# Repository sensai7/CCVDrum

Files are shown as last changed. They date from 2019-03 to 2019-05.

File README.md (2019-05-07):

# CCVDrum
Energia code and Kicad files for a Korg Volca Drum MIDI CC board

Board

In the Korg Volca Drum there's a hidden menu when you press the edit/step to 
change five adittional settings for each part and layer: bit resolution, 
overdrive, wave folding, pan, and pre-amp gain.

This repository contains the code, schematic, and PCB files to build and 
program a circuit board to control the 'hidden' paramenters from a Korg Volca 
Drum, having one dedicated knob control for each one and being able to select 
the first, second, or both layers with the provided push buttons. 
The circuit is based on a MSP430G2553, a common and cheap microprocessor from 
Texas Instruments, and it's coded in Energia, an Arduino port for TI 
processors, bringing the simplicity of the Wiring language and the huge 
Arduino community projects available to the Texas Instruments MCU ecosystem.

Some features:

* The board is designed to fit inside a 1590B enclosure, a really common 
and cheap enclosure model for guitar pedals.
* The power plug is a 2.1mm barrel jack and with the current Voltage Regulator 
model, Voltages from 5V to 20V are fine.
* There's a optional MIDI input to use as MIDI thru if you need to chain your 
devices.

The Volca must be [up to date](https://www.korg.com/us/support/download/product/0/809/#software), or at least in version 1.11 which changed a critical bug on the MIDI implementation (BIT knob won't work and the others would be changed). It must also be set in Split Channel Mode, the CC messages needed (BIT, DRV,... etc) are not available in the Single Channel Mode. My unit came with Split mode by default, but to check and change it, turn it on while holding ●RECORD, then press one of the channels to select it, then press it again to change it to channels 1-6. Press the ●RECORD button again when your unit's screen shows [MID 1--6](https://i.imgur.com/e5hpA2r.jpg).

The easiest way to flash a different firmware would be owning a MSP430G2 
(MSP-EXP430G2) launchpad, or the newer MSP430G2ET (MSP-EXP430G2ET) LaunchPad, 
place your MCU in the LaunchPad socket and flash the new code using Energia. 

Useful links

 * Korg Volca Drum official site: https://www.korg.com/us/products/dj/volca_drum/
 * Energia Project site: http://energia.nu
 * KiCad footprints and 3D models http://smisioto.no-ip.org/elettronica/kicad/kicad-en.htm

Datasheets

 * MSP430G2553 Mixed Signal Microcontroller http://www.ti.com/lit/ds/symlink/msp430g2553.pdf
 * 6N139 High Speed Optocoupler https://www.vishay.com/docs/83605/6n139.pdf
 * 74HC14 Hex inverting Schmitt trigger https://assets.nexperia.com/documents/data-sheet/74HC_HCT14.pdf
 * LM1117IMP-3.3 LDO Voltage Regulator http://www.ti.com/lit/ds/symlink/lm1117.pdf
 
 (Only in older versions):
 * AMS1117-3.3 1A LOW DROPOUT VOLTAGE REGULATOR http://www.advanced-monolithic.com/pdf/ds1117.pdf
 * 74AUP1G17 SINGLE SCHMITT-TRIGGER BUFFER https://www.diodes.com/assets/Datasheets/74AUP1G17.pdf

TODO

 * Fix minor bugs

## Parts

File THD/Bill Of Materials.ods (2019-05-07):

Disclaimer: The purchase links are not really curated, you can most probably find the same items for cheaper if you browse more alternatives, you usually have everything you need in Tayda/ Ebay / Aliexpress and most importantly, your local electronic supplies store.
 | I’m not associated in any way with any of the vendors of any of these components.
Designator | Package or sizes | Component | Value or model | purchase link | alt link | Comments
C1 | THT 5.00mm | Capacitor | 10n |  |  | I suggest getting the capacitors at your local electronic supply store so you avoid buying 100+ pieces of the same value. Alternatively the “assorted capacitor” packs online are handy.
C2 | THT 5.00mm | Capacitor | 330n
C3 | THT 5.00mm | Capacitor | 100n
C4 | THT 5.00mm | Capacitor | 10n
C5 | THT 5.00mm | Capacitor | 100n
D1 | LED 3mm | LED | LED
D2 | LED 3mm | LED | LED
D3 | LED 3mm | LED | LED
D4 | LED 3mm | LED | LED
D5 | LED 3mm | LED | LED
D6 | LED 3mm | LED | LED
J1 | Barrel jack | Barrel jack | Barrel jack
J4 | DIN-5 | Female MIDI | MIDI_in | https://www.ebay.com/itm/2pcs-PCB-Panel-PC-Mount-Right-Angle-MIDI-Female-DIN5-DIN-5-Pin-Connector-Socket/300632125472
J5 | DIN-5 | Female MIDI | MIDI_out
R1 | R_Axial | Resistor | 47k
R2 | R_Axial | Resistor | 68 |  |  | The value RLED depends on the LED model, the color of the LED and the luminosity you want. Take in consideration the MSP430 can only output up to 6mA per pin
R3 | R_Axial | Resistor | 220 |  |  | RLED = (3.3 – Vdrop) / I
R4 | R_Axial | Resistor | RLED |  |  | Assuming 2V drop from a red led @ I = 5mA
R5 | R_Axial | Resistor | RLED |  |  | RLED = (3.3 – 2) / 5mA = 260
 |  |  |  |  |  | To choose an standard value from E24 resistors RLED =270 ohm (or 300/330ohm) to ensure ILED is between 4ma and 5ma
R7 | R_Axial | Resistor | RLED
R8 | R_Axial | Resistor | 68
R9 | R_Axial | Resistor | 270
R10 | R_Axial | Resistor | RLED
R11 | R_Axial | Resistor | RLED
R12 | R_Axial | Resistor | RLED
RV1 | alps-rk09k1130ah1 | Potentiometer | 10k | https://www.taydaelectronics.com/potentiometer-variable-resistors/rotary-potentiometer/linear/10k-ohm-linear-taper-potentiometer-round-knurled-plastic-shaft-p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 | https://www.ebay.com/itm/20PCS-RV09-Type-Vertical-Adjustable-Potentiometer-Variable-Resistor-10K/183206858753 | Tayda has also some nice metal-knob models. The value is not really relevant, as long as you keep it from 1k to 100k to avoid weird behaviors
RV2 | alps-rk09k1130ah1 | Potentiometer | 10k
RV3 | alps-rk09k1130ah1 | Potentiometer | 10k
RV4 | alps-rk09k1130ah1 | Potentiometer | 10k
RV5 | alps-rk09k1130ah1 | Potentiometer | 10k
RV6 | alps-rk09k1130ah1 | Potentiometer | 10k
SW1 | 6mm THT vertical | Push button | 6mm | https://www.aliexpress.com/item/20PCS-4Pin-6-6-Micro-Tact-Push-Button-Switches-DIP-6x6x4-3-5-6-8-10/32963297826.html | https://www.ebay.com/itm/20PCS-6-6-6mm-Tact-Tactile-Push-Button-Switch-DIP-4Pin-NEW/391462868531
SW2 | 6mm THT vertical | Push button | 6mm
U1 | DIP-20 | MCU | MSP430G2533 | https://www.ebay.com/itm/1pcs-M430G2553-ORIGINAL-MSP430G2553IN20-MSP430G2553-MCU-IC-TI-DIP-20-NEW/172847287897 |  | Any 20-pin MSP430G2 “should” work too
U2 | TO-220-3 | LDO Regulator | LM1117IMP-3.3
U3 | DIP-14 | Hex schmitt trigger | 74HC14

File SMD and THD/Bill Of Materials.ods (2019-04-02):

Disclaimer: The purchase links are not really curated, you can most probably find the same items for cheaper if you browse more alternatives, you usually have everything you need in Tayda/ Ebay / Aliexpress and most importantly, your local electronic supplies store.
 | I’m not associated in any way with any of the vendors of any of these components.
Designator | Package or sizes | Component | Value or model | purchase link | alt link | Comments
C1 | THT 5.00mm | Capacitor | 330n |  |  | I suggest getting the capacitors at your local electronic supply store so you avoid buying 100+ pieces of the same value. Alternatively the “assorted capacitor” packs online are handy.
C2 | THT 5.00mm | Capacitor | 100n
C3 | THT 5.00mm | Capacitor | 1n
C4 | THT 5.00mm | Capacitor | 10n
C5 | THT 5.00mm | Capacitor | 100n
D1 | 0805 | LED | LED | https://www.ebay.com/itm/100PCS-White-Red-Blue-Yellow-Orange-SMD-LED-0805-2mm-1-2mm-NEW/232397105931 |  | Since it’s a small component the pads have been made bigger. A slightly bigger LED would probably fit as well.
D2 | 0805 | LED | LED
D3 | 0805 | LED | LED
D4 | 0805 | LED | LED
D5 | 0805 | LED | LED
D6 | 0805 | LED | LED
J1 | USB_Micro-B | Female USB | USB_B_μ | https://www.ebay.com/itm/10Pcs-Micro-USB-Type-B-Female-5Pin-Horns-type-Socket-PCB-Solder-Connector/171349298330 |  | Take in consideration the current footprint as two long drill holes to fir those metal tips on the sides
J2 | 2.54mm pitch | Pin Header | 1x4 Vertical | www.ebay.com/itm/10PCS-40Pin-2-54mm-Single-Row-Straight-Male-Pin-Header-Strip-PBC-Ardunio-GM/262136738129 |  | Not necessary if you don’t plan to mod or re-program the MCU yourself
J3 | DIN-5 | Female MIDI | MIDI_out | https://www.ebay.com/itm/2pcs-PCB-Panel-PC-Mount-Right-Angle-MIDI-Female-DIN5-DIN-5-Pin-Connector-Socket/300632125472 |  | The footprint has enough clearance in case you purchase those slightly bigger versions
R1 | R_Axial | Resistor | 47k
R2 | R_Axial | Resistor | RLED |  |  | The value RLED depends on the LED model, the color of the LED and the luminosity you want. Take in consideration the MSP430 can only output up to 6mA per pin
R3 | R_Axial | Resistor | RLED |  |  | RLED = (3.3 – Vdrop) / I
R4 | R_Axial | Resistor | RLED |  |  | Assuming 2V drop from a red led @ I = 6mA
R5 | R_Axial | Resistor | RLED |  |  | RLED = (3.3 – 2) / 6mA = 133.3 ohm
R6 | R_Axial | Resistor | RLED |  |  | To choose an standard value RLED =150 ohm to ensure ILED is between 5ma and 6ma
R7 | R_Axial | Resistor | RLED
R8 | R_Axial | Resistor | 68ohm
R9 | R_Axial | Resistor | 68ohm
R10 | R_Axial | Resistor | 1k
RV1 | alps-rk09k1130ah1 | Potentiometer | 10k | https://www.taydaelectronics.com/potentiometer-variable-resistors/rotary-potentiometer/linear/10k-ohm-linear-taper-potentiometer-round-knurled-plastic-shaft-p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 | https://www.ebay.com/itm/20PCS-RV09-Type-Vertical-Adjustable-Potentiometer-Variable-Resistor-10K/183206858753 | Tayda has also some nice metal-knob models. The value is not really relevant, as long as you keep it from 1k to 100k to avoid weird behaviors
RV2 | alps-rk09k1130ah1 | Potentiometer | 10k
RV3 | alps-rk09k1130ah1 | Potentiometer | 10k
RV4 | alps-rk09k1130ah1 | Potentiometer | 10k
RV5 | alps-rk09k1130ah1 | Potentiometer | 10k
RV6 | alps-rk09k1130ah1 | Potentiometer | 10k
SW1 | 6mm THT vertical | Push button | 6mm | https://www.aliexpress.com/item/20PCS-4Pin-6-6-Micro-Tact-Push-Button-Switches-DIP-6x6x4-3-5-6-8-10/32963297826.html | https://www.ebay.com/itm/20PCS-6-6-6mm-Tact-Tactile-Push-Button-Switch-DIP-4Pin-NEW/391462868531
SW2 | 7mm THT vertical | Push button | 6mm
U1 | DIP-20 | MCU | MSP430G2533 | https://www.ebay.com/itm/1pcs-M430G2553-ORIGINAL-MSP430G2553IN20-MSP430G2553-MCU-IC-TI-DIP-20-NEW/172847287897 |  | Any 20-pin MSP430G2 “should” work too
U2 | SOT-223-3 | LDO Regulator | AMS1117-3.3 | https://www.ebay.com/itm/10Pcs-AMS1117-3-3-LM1117-3-3V-1A-SOT-223-Voltage-Regulator-Nice-WD/312443168863
U3 | SOT-23-5 | Triggered Buffer | 74AUP1G17 | https://www.ebay.com/itm/10pcs-PJ-74AUP1G17GW-125-SOT-23-5-Low-power-Schmitt-trigger-buffer/253831344705 |  | Any Buffer with the same package and pinout suited for 3.3V operation should work just as well

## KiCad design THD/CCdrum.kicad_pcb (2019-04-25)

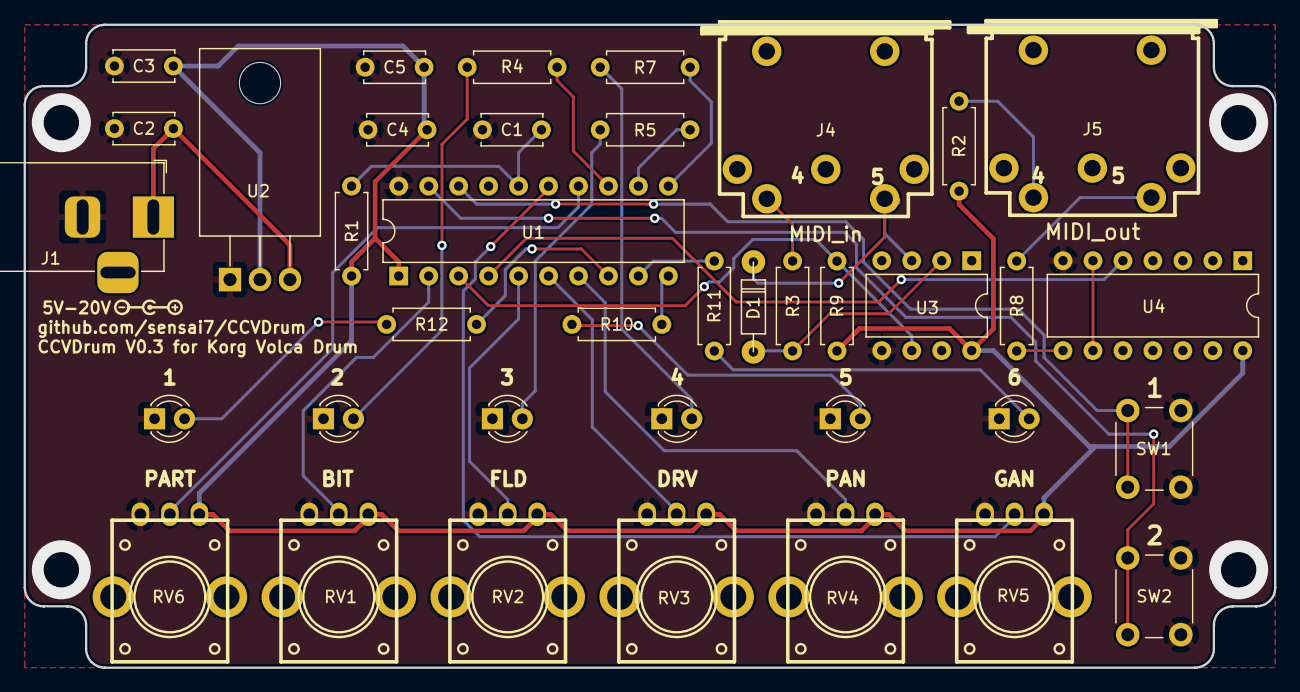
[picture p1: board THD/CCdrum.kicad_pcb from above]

Board: 2 copper layers, 106.0 x 54.5 mm, 38 parts (0 on the bottom side), 33 nets.

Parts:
C1, C4: 10; C_Disc_D5.0mm_W2.5mm_P5.00mm
C2: 330; C_Disc_D5.0mm_W2.5mm_P5.00mm
C3, C5: 100; C_Disc_D5.0mm_W2.5mm_P5.00mm
D1: 1N4148; diode_do35
D2: 1; LED_D3.0mm
D3: 2; LED_D3.0mm
D4: 3; LED_D3.0mm
D5: 4; LED_D3.0mm
D6: 5; LED_D3.0mm
D7: 6; LED_D3.0mm
J1: Barrel_Jack; BarrelJack_Horizontal
J4: MIDI_in; din-5
J5: MIDI_out; din-5
R1: 47k; R_Axial_DIN0207_L6.3mm_D2.5mm_P7.62mm_Horizontal
R2, R8: 68; R_Axial_DIN0207_L6.3mm_D2.5mm_P7.62mm_Horizontal
R3: 220; R_Axial_DIN0207_L6.3mm_D2.5mm_P7.62mm_Horizontal
R4, R5, R7, R10, R11, R12: RLED; R_Axial_DIN0207_L6.3mm_D2.5mm_P7.62mm_Horizontal
R9: 270; R_Axial_DIN0207_L6.3mm_D2.5mm_P7.62mm_Horizontal
RV1, RV2, RV3, RV4, RV5, RV6: 10k; trimmer_alps-rk09k1130ah1
SW1, SW2: SW_Push; SW_PUSH_6mm_H4.3mm
U1: MSP430G2533; DIP-20_W7.62mm
U2: LM1117IMP-3.3; TO-220-3_Horizontal_TabDown
U3: 6N139; DIP-8_W7.62mm
U4: 74HC14; DIP-14_W7.62mm

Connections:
+3V3: C3.1, C4.1, C5.1, R1.1, R2.1, R9.1, RV1.1, RV2.1, RV3.1, RV4.1, RV5.1, RV6.1, U1.1, U2.2, U3.8, U4.14
+5V: C2.1, J1.1, U2.3
BIT: RV1.2, U1.2
DRV: RV3.2, U1.6
FLD: RV2.2, U1.5
GAN: RV6.2, U1.14
GND: C1.2, C2.2, C3.2, C4.2, C5.2, D2.1, D3.1, D4.1, D5.1, D6.1, D7.1, J1.2, RV1.3, RV2.3, RV3.3, RV4.3, RV5.3, RV6.3, SW1.1, SW2.1, U1.20, U2.1, U3.5, U4.7
LED_P1: R4.1, U1.13
LED_P2: R5.1, U1.12
LED_P3: R7.1, U1.11
LED_P4: R10.1, U1.10
LED_P5: R11.1, U1.9
LED_P6: R12.1, U1.8
unnamed: C1.1, R1.2, U1.16
unnamed: D1.1, R3.1, U3.2
unnamed: D1.2, J4.5, U3.3
unnamed: D2.2, R4.2
unnamed: D3.2, R5.2
unnamed: D4.2, R7.2
unnamed: D5.2, R10.2
unnamed: D6.2, R11.2
unnamed: D7.2, R12.2
unnamed: J4.4, R3.2
unnamed: J5.4, R2.2
unnamed: J5.5, R8.1
unnamed: R8.2, U4.8
unnamed: U4.6, U4.9
PAN: RV4.2, U1.7
PART: RV5.2, U1.15
PUSH_L1: SW1.2, U1.18
PUSH_L2: SW2.2, U1.19
RXD: R9.2, U1.3, U3.6
TXD: U1.4, U4.5

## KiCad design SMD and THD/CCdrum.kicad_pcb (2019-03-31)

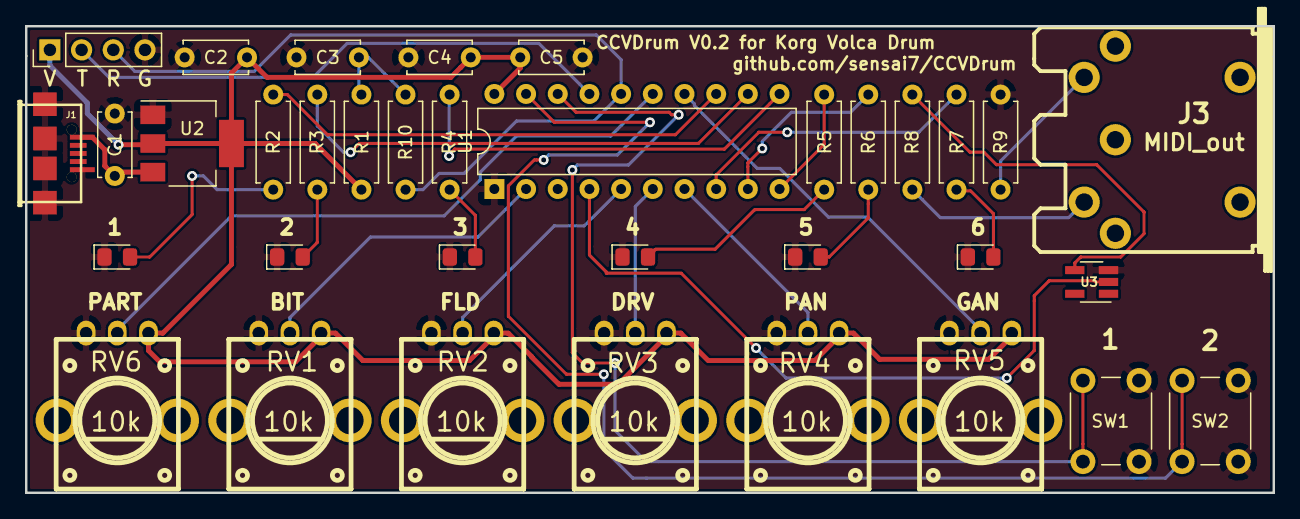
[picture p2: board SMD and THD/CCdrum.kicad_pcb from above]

Board: 2 copper layers, 100.0 x 37.4 mm, 35 parts (0 on the bottom side), 30 nets.

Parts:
C1: 330; C_Disc_D5.0mm_W2.5mm_P5.00mm
C2, C5: 100; C_Disc_D5.0mm_W2.5mm_P5.00mm
C3: 1n; C_Disc_D5.0mm_W2.5mm_P5.00mm
C4: 10; C_Disc_D5.0mm_W2.5mm_P5.00mm
D1: 1; LED_0805_2012Metric_Pad1.15x1.40mm_HandSolder
D2: 2; LED_0805_2012Metric_Pad1.15x1.40mm_HandSolder
D3: 3; LED_0805_2012Metric_Pad1.15x1.40mm_HandSolder
D4: 4; LED_0805_2012Metric_Pad1.15x1.40mm_HandSolder
D5: 5; LED_0805_2012Metric_Pad1.15x1.40mm_HandSolder
D6: 6; LED_0805_2012Metric_Pad1.15x1.40mm_HandSolder
J1: USB_B_μ; conn_usb_B_micro_smd-2
J2: Program; PinHeader_1x04_P2.54mm_Vertical
J3: MIDI_out; din-5
R1: 47k; R_Axial_DIN0207_L6.3mm_D2.5mm_P7.62mm_Horizontal
R2, R3, R4, R5, R6, R7: RLED; R_Axial_DIN0207_L6.3mm_D2.5mm_P7.62mm_Horizontal
R8, R9: 68; R_Axial_DIN0207_L6.3mm_D2.5mm_P7.62mm_Horizontal
R10: 1k; R_Axial_DIN0207_L6.3mm_D2.5mm_P7.62mm_Horizontal
RV1, RV2, RV3, RV4, RV5, RV6: 10k; trimmer_alps-rk09k1130ah1
SW1, SW2: SW_Push; SW_PUSH_6mm_H4.3mm
U1: MSP430G2533; DIP-20_W7.62mm
U2: AMS1117-3.3; SOT-223-3_TabPin2
U3: 74AUP1G17; SOT-23-5_HandSoldering

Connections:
+3V3: C2.1, C4.1, C5.1, J2.1, R1.1, RV1.1, RV2.1, RV3.1, RV4.1, RV5.1, RV6.1, U1.20, U2.2
+5V: C1.1, J1.1, U2.3
BIT: RV1.2, U1.2
DRV: RV3.2, U1.6
FLD: RV2.2, U1.5
GAN: RV5.2, U1.14
GND: C1.2, C2.2, C3.2, C4.2, C5.2, D1.1, D2.1, D3.1, D4.1, D5.1, D6.1, J1.5, J2.4, R9.2, RV1.3, RV2.3, RV3.3, RV4.3, RV5.3, RV6.3, SW1.1, SW2.1, U1.1, U2.1, U3.3
LED_P1: R2.1, U1.13
LED_P2: R3.1, U1.12
LED_P3: R4.1, U1.11
LED_P4: R5.1, U1.10
LED_P5: R6.1, U1.9
LED_P6: R7.1, U1.8
unnamed: C3.1, R1.2, R10.2
unnamed: D1.2, R2.2
unnamed: D2.2, R3.2
unnamed: D3.2, R4.2
unnamed: D4.2, R5.2
unnamed: D5.2, R6.2
unnamed: D6.2, R7.2
unnamed: J3.4, R9.1
unnamed: J3.5, R8.1
unnamed: R8.2, U3.4
PAN: RV4.2, U1.7
PART: RV6.2, U1.15
PUSH_L1: SW1.2, U1.18
PUSH_L2: SW2.2, U1.19
RST: J2.3, R10.1, U1.16
TEST: J2.2, U1.17
TXD: U1.4, U3.2

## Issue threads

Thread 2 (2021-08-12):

PCB availability?

PRKid1, 2021-08-12:
Hello!

I was wondering if you are still selling the PCA (assembled) for this project.  I just got a Volca Drum and ran into your post on Reddit.  Thank you!

gr34tmedia, 2021-08-22:
Hi there,  i happen to have the components for the controller and im willingto build you one. You still want one ? Get in contact: lp [at] gr34t.de cheers.

PRKid1, 2021-08-23:
Yes, I am still interested.  I went to that link, yet, not clear where to place request.  Will try again.

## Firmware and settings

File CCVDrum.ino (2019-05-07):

// Pin connections
// Complete pinmap on http://energia.nu/pinmaps/img/LaunchPadMSP430G2452-v1.5.jpg
#define POT_BIT 2
#define POT_FLD 5
#define POT_DRV 6
#define POT_PAN 7
#define POT_GAN 14
#define POT_PART 15
#define LED_P1 13
#define LED_P2 12
#define LED_P3 11
#define LED_P4 10
#define LED_P5 9
#define LED_P6 8
#define PUSH_L1 18
#define PUSH_L2 19

//operation variables
const unsigned int numReadings = 10;
const unsigned int potPort[6] = {POT_PART, POT_BIT, POT_FLD, POT_DRV, POT_PAN, POT_GAN};
const unsigned int ledPort[6] = {LED_P1, LED_P2, LED_P3, LED_P4, LED_P5, LED_P6};
const unsigned int pushPort[2] = {PUSH_L1, PUSH_L2};
const unsigned int CCValues[5] = {0x31, 0x32, 0x33, 0x0A, 0x34}; //BIT, FLD, DRV, PAN, GAN //Complete Midi implementation on https://www.korg.com/us/support/download/product/0/809/
unsigned int readings[6][numReadings];
unsigned int readIndex = 0;
unsigned int total[6] = {0, 0, 0, 0, 0};
unsigned int average[6] = {0, 0, 0, 0, 0};
unsigned int outputValue[6] = {0, 0, 0, 0, 0};
unsigned int previousValue[6] = {0, 0, 0, 0, 0};
unsigned int part = 0;
unsigned int layer = 0;
bool push[2] = {1, 1};
bool previousPush[2] = {1, 1};
bool pushFlag = 0;

//timing variables
unsigned long previousMillis = 0;
const unsigned int interval = 10; //(milliseconds for each midi send)

void setup(){
	Serial.begin(31250); 

	//Setup LEDs
	for (int i = 0; i < 6; i++){
		pinMode(ledPort[i], OUTPUT);
		digitalWrite(ledPort[i], LOW);
	}

	//Read pot initial status
	for (int j = 0; j < numReadings; j++) {
		digitalWrite(ledPort[j%6], HIGH);
		for (int i = 0; i < 6; i++){
			readings[i][j] = analogRead(potPort[i]);
			total[i] += readings[i][j];
		}
		delay(50); 
		digitalWrite(ledPort[j%6], LOW);
		delay(50);
	} 

	//Setup buttons
//	P2SEL = 0;
//	P2DIR = BIT6+BIT7; //setup XIN and XOUT as digital outputs
//	pinMode(PUSH_L1, INPUT_PULLUP);
//	pinMode(PUSH_L2, INPUT_PULLUP);
}

void loop(){
	//Averaging and updating pot status
	for (int i = 0; i < 6; i++){
		average[i] = total[i] / numReadings;
		outputValue[i] = average[i] >> 3;
		total[i] -= readings[i][readIndex];
		readings[i][readIndex] = analogRead(potPort[i]);
		total[i] += readings[i][readIndex];
	}
	readIndex = (readIndex + 1) % (numReadings);

	// to be executed once every 'interval' miliseconds
	unsigned long currentMillis = millis();
	if (currentMillis - previousMillis > interval){	 
		previousMillis = currentMillis;

		//pots
		part = map(outputValue[0], 0, 127, 5, 0);
		for (int i = 1; i < 6; i++){
			if (outputValue[i] != previousValue[i]){
				digitalWrite(ledPort[i], HIGH);
				Serial.write(0xB0 + part); 
				Serial.write(CCValues[i - 1]);
				Serial.write(127 - outputValue[i]);
				previousValue[i] = outputValue[i];
				digitalWrite(ledPort[i], LOW);
			}
		}

//		//Buttons
//		for (int i = 0; i < 2; ++i){
//			previousPush[i] = push[i];
//			push[i] = digitalRead(pushPort[i]);
//		}
//		if (!push[0] && !push[1]){
//			pushFlag = 1;
//		}
//		if (!pushFlag){ //only one button
//			if (push[0] && !previousPush[0]){
//				Serial.write(0xB0 + part);
//				Serial.write(14);
//				Serial.write(0xff);
//			}
//			if (push[1] && !previousPush[1]){
//				Serial.write(0xB0 + part);
//				Serial.write(15);
//				Serial.write(0xff);
//			}
//		}
//		else{ // both buttons
//			if(push[0] | push[1] == 0){
//				pushFlag = 0;
//				Serial.write(0xB0 + part);
//				Serial.write(16);
//				Serial.write(0xff);
//			}
//		}

		//LEDs
//		if (!push[0] | !push[1]){
//			if(!push[0] | pushFlag){
//				digitalWrite(ledPort[0], HIGH);
//				digitalWrite(ledPort[1], HIGH);
//				digitalWrite(ledPort[2], HIGH);
//			}
//			if (!push[1] | pushFlag){
//				digitalWrite(ledPort[3], HIGH);
//				digitalWrite(ledPort[4], HIGH);
//				digitalWrite(ledPort[5], HIGH);
//			}
//		}
//		else{
			for (int i = 0; i < 6; i++){
				if (i != part){
					digitalWrite(ledPort[i], LOW);
				}
			}
			digitalWrite(ledPort[part], HIGH);
//		}

	} 
}

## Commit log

2019-03-20 Added KiCad Project
    [CCdrum-B.Cu.gbr, CCdrum-B.Mask.gbr, CCdrum-B.Paste.gbr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]
2019-03-21 Changed 3D models
    [CCdrum.kicad_pcb]
2019-03-25 Re-annotated components
    [CCdrum-B.Cu.gbr, CCdrum-B.Mask.gbr, CCdrum-B.Paste.gbr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]
2019-03-25 Added a BOM table
    [Bill Of Materials.ods]
2019-03-25 removed BOM TODO
2019-03-30 New Schematic
    [CCdrum.sch]
2019-03-30 New PCB Arrangement
    [CCdrum.kicad_pcb, CCdrum.sch]
2019-03-30 PCB Routed
    [CCdrum-B.Cu.gbr, CCdrum-B.Mask.gbr, CCdrum-B.Paste.gbr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]
2019-03-31 Added Decoupling caps
    [CCdrum.sch]
2019-03-31 New PCB design
    [CCdrum-B.Cu.gbr, CCdrum-B.Mask.gbr, CCdrum-B.Paste.gbr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]
2019-03-31 USB changed, small errors on board
    [CCdrum-B.Cu.gbr, CCdrum-B.Mask.gbr, CCdrum-B.Paste.gbr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]
2019-04-01 Code for the V0.2 board
2019-04-02 Updated BOM
    [Bill Of Materials.ods]
2019-04-02 Removed comment text
    [CCdrum.sch]
2019-04-02 added button detection
2019-04-02 push buttons change layers via CC
2019-04-15 1590B 0.3 version added
    [Bill Of Materials.ods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]
2019-04-15 removed mask from screw holes
    [CCdrum.kicad_pcb]
2019-04-16 Updated silkscreen + debug
    [CCdrum-B.Cu.gbr, CCdrum-B.Mask.gbr, CCdrum-B.Paste.gbr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]
2019-04-17 changed buffer
    [CCdrum-B.Cu.gbr, CCdrum-B.Mask.gbr, CCdrum-B.Paste.gbr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]
2019-04-21 Changed the MIDI out pullup resistor
    [CCdrum-B.Cu.gbr, CCdrum-B.Mask.gbr, CCdrum-B.Paste.gbr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]
2019-04-25 Fixed the mcu supply
    [CCdrum-B.Cu.gbr, CCdrum-B.Mask.gbr, CCdrum-B.Paste.gbr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]
2019-05-07 Removed confusing information from the BOM and updated it a little
    [Bill Of Materials.ods]
